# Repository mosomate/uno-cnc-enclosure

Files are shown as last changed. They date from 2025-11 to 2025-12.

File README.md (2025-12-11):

# What is UNO CNC Enclosure?
An easy to print and assemble enclosure for [Arduino UNO](https://docs.arduino.cc/hardware/uno-rev3/) and CNC Shield V3. The fan at the front keeps the electronics cool and the "patch panel" at the back ensures easy cable management.

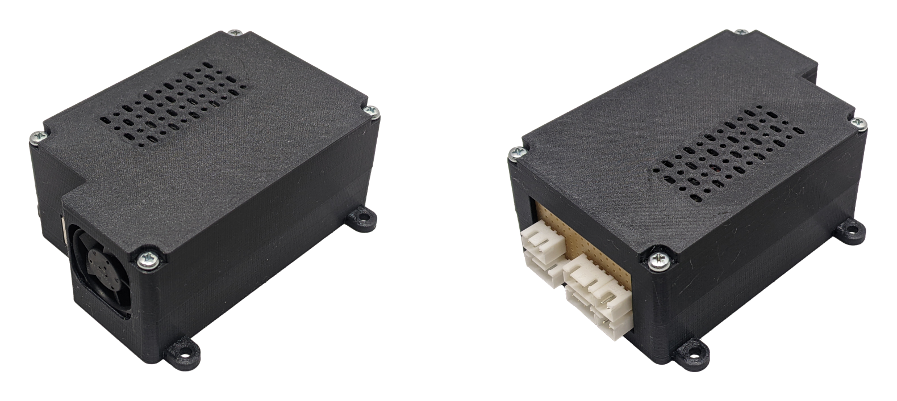
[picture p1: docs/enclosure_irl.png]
Actual photo of the enclosure


# Disclaimer
**I don't take any responsibilities for injuries and/or any damage caused by this design. Build at you own risk!**

# 3D printing
You can download all the necessary STL files for 3D printing from the project's Thingiverse page:

[Enclosure for Arduino UNO + CNC Shield](https://www.thingiverse.com/thing:7212313)

Please refer the Thingiverse page to pick the right STL for your needs and for printing tips!

# BOM
**General**
- 1 pc of 3D printed **bottom** part
- 1 pc of 3D printed **top** part
- 1 [Arduino UNO](https://docs.arduino.cc/hardware/uno-rev3/) board
- 1 CNC Shield and [Pololu steppers](https://www.pololu.com/product/1182) (or stepper boards with the same form factor) for each axis
- 2 pcs of **M3x4** screws. These are not easy to source, you better shorten longer screws
- 4 pcs of **M3x25** screws
- 1 fan. It can be a **25x25x10 mm** fan, or **Ebm-papst**'s fabulous **25x25x8 mm** fan. If you pick this, a fan grill (STL can be found on the Thingiverse page) is also needed
- 1 pair of **0.1"** pitch header pins (for connecting the fan to the CNC Shield. See assembly step 4)
- 1 patch panel (see the next section)
- Some **20 AWG** wire for the power and **24-26 AWG** wire for the rest of the connections from the CNC Shield to the patch panel

**For the patch panel**
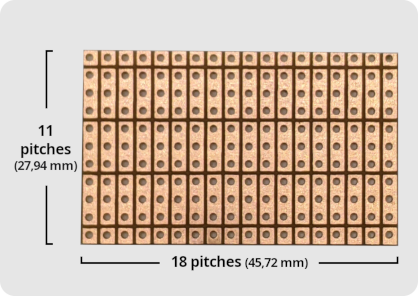
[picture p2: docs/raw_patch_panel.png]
Raw patch panel
- Prototyping PCB with **0.1"** pitch and the measurements shown below: 
- ? pcs of any wire-to-board connector with **0.1"** pitch. My recommendation is **JST**'s [XH series](https://www.jst-mfg.com/product/pdf/eng/eXH.pdf) connectors (amount and type of these connectors are dependent on your needs)
- ? pcs of pin header connectors to wire the patch panel to the CNC Shield (amount and type of these connectors are dependent on your needs). **Ninigi**'s [NSR series](https://ninigi.com/gb/en/product/ninigi/pin-headers/nsr-01/112937/) connectors are a good example

# Assembly
1. Tap **M3** threads into the bottom part's four corner holes and the two Arduino mounting points (indicated by yellow arrows). A regular M3 tap drill may be sufficient for the corner holes, but not for the mounting points. I simply cut a vertical notch into a M3 screw with a hacksaw. Apply some pressure while driving in the screw and the sharp edges do the rest.
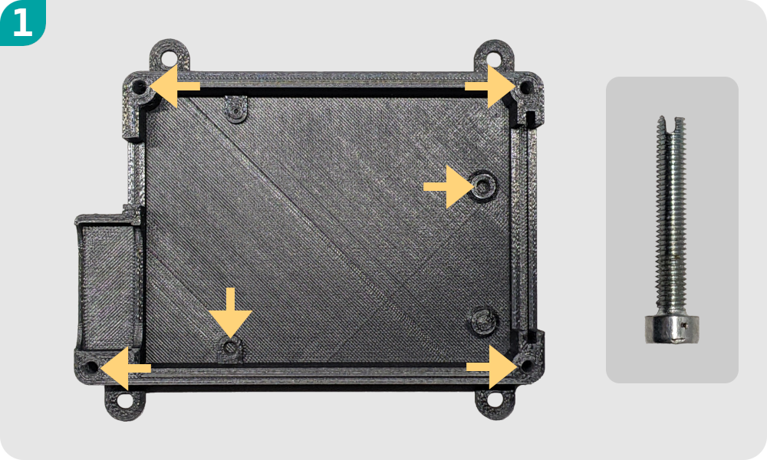
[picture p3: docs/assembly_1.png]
M3 threads in the bottom

2. Mount the Arduino UNO with the **M3x4** screws (mounting points are indicated with yellow arrows) **(A)**. Then, attach the CNC Shield **(B)**.
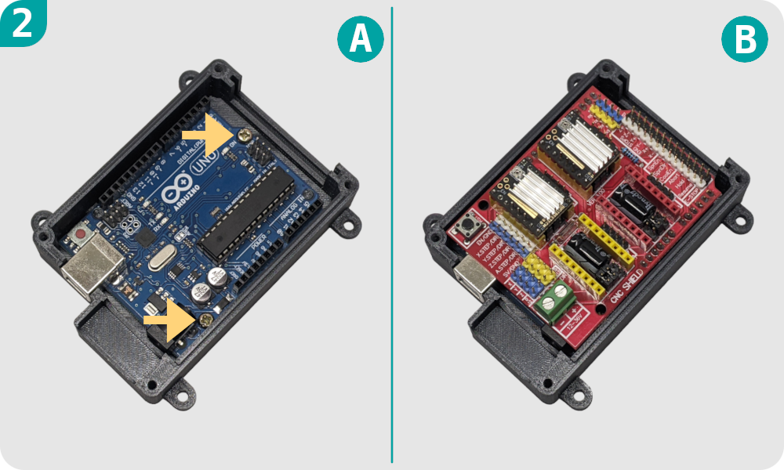
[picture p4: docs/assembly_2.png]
UNO mounting points

3. Solder the connectors to the patch panel's PCB. See an example layout below **(A)**. Wire the header pins on the CNC Shield to the patch panel. Oh, boy... This won't be easy. After trying many options I came up with a **recommendation**. For each cable: **1.** cut off the end of the contact to make it shorter. **2.** Strip the wire and fold the conductor under the insulation. **3.** Crimp the contact to the wire. **4.** Put a piece of heatshrink tube around the contact for safety. Check the steps below **(B)**. Then cut the wire to length and solder these cables to the right pads at the patch panel. Pre-crimped cables also can be used, but the space between the cables and the top will be a little tighter. Don't forget to connect the power as well!
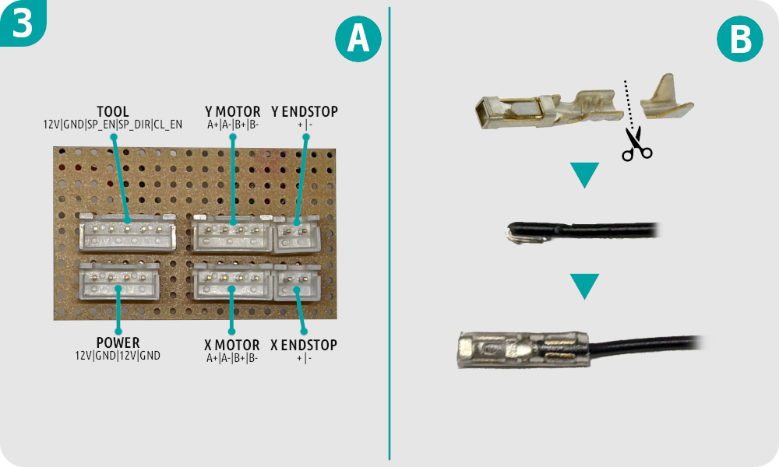
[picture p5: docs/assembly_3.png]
Patch panel and wiring

4. Solder a pair of **0.1"** pitch header pins on the cooling fan's cable and wrap it with heatshrink tube **(A)**. The cable should reach the first two pin slots on the far side of "A" axis' stepper socket **(B)**.
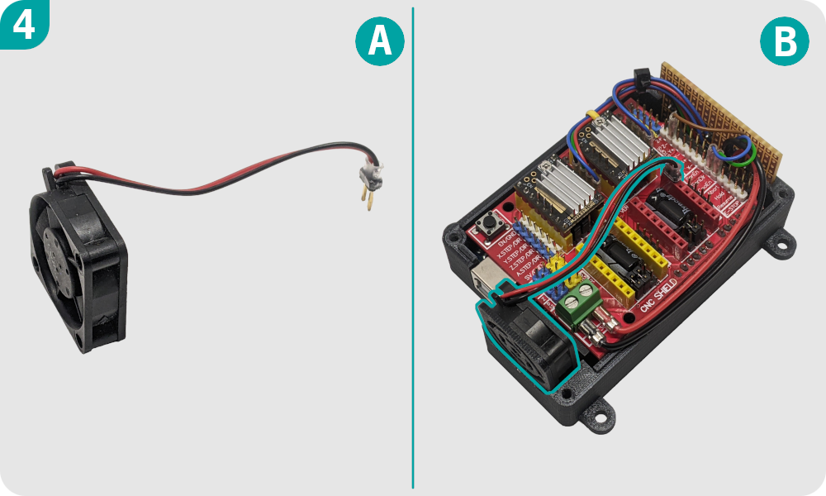
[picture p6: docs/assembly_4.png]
Cooling fan wiring

5. Slide the top part to the bottom. Insert the four **M3x25** screws into the corners and tighten them firmly. **Congratulations!** Now you have a handsome CNC Shield enclosure!

# License
Shield: [][cc-by-nc]

This work is licensed under a
[Creative Commons Attribution-NonCommercial 4.0 International License][cc-by-nc].

[][cc-by-nc]

[cc-by-nc]: https://creativecommons.org/licenses/by-nc/4.0/
[cc-by-nc-image]: https://licensebuttons.net/l/by-nc/4.0/88x31.png
[cc-by-nc-shield]: https://img.shields.io/badge/License-CC%20BY--NC%204.0-lightgrey.svg

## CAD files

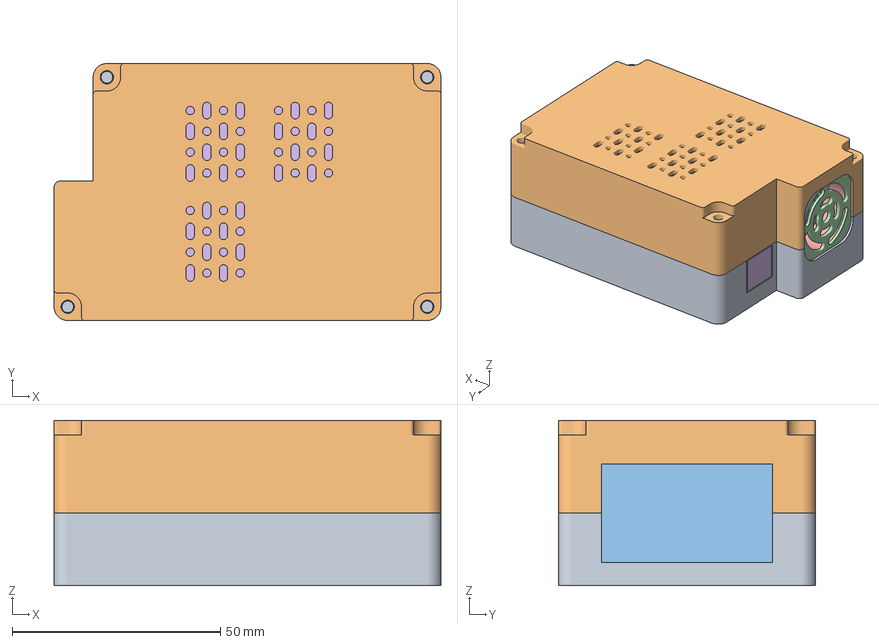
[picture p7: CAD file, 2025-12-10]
Enclosure.FCStd
92.9 x 61.7 x 39.7 mm
Bottom
Top
Breakout
Fan_grill
Fan
Board_v2

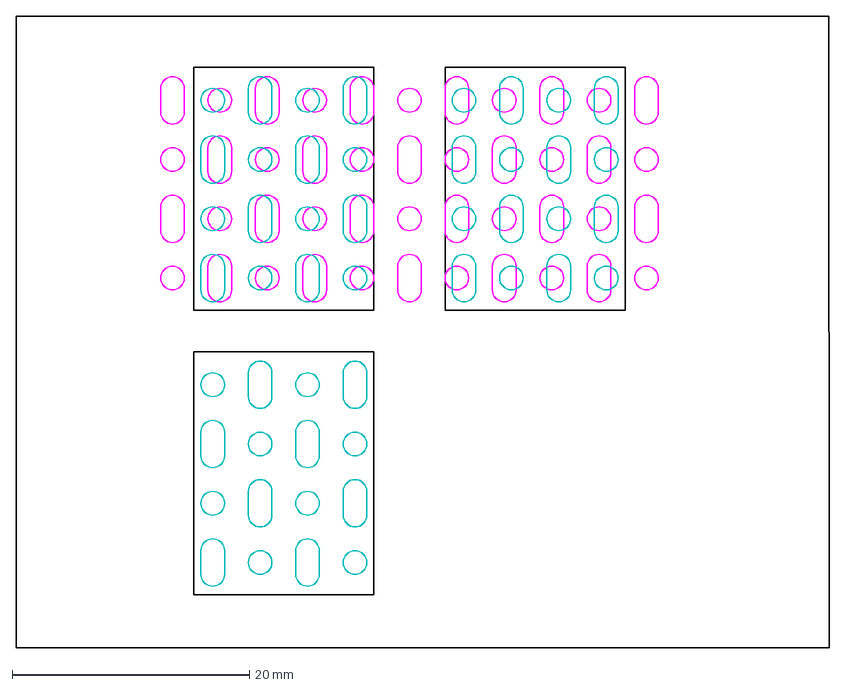
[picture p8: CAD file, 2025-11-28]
Top_vent_patterns.dxf
68.6 x 53.3 mm

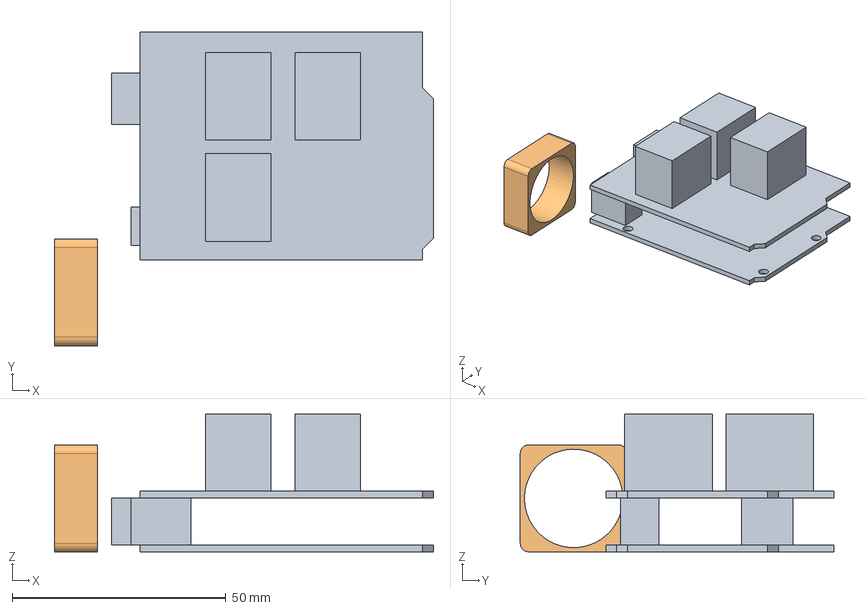
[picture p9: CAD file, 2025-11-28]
Utils.FCStd
88.6 x 73.3 x 32.2 mm
Board
Fan

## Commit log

2025-11-28 Basic README
    [Enclosure.FCStd, Top_vent_patterns.dxf, Utils.FCStd]
2025-11-30 BOM for README
2025-11-30 1st step for assembly in README
2025-11-30 Assembly step 2 for README
2025-12-10 Fixed flow deflector distance
    [Enclosure.FCStd]
2025-12-10 Step 3 added to assembly
2025-12-10 Step 4 added to assembly
2025-12-11 Fixed assembly step 3
